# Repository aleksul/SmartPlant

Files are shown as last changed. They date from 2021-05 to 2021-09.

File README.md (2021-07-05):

# SmartPlant

SmartPlant is a simple project that will help you automate watering of your plants.

## Design

Simple and industrial design is easy for 3d printing. Look at this beauty:

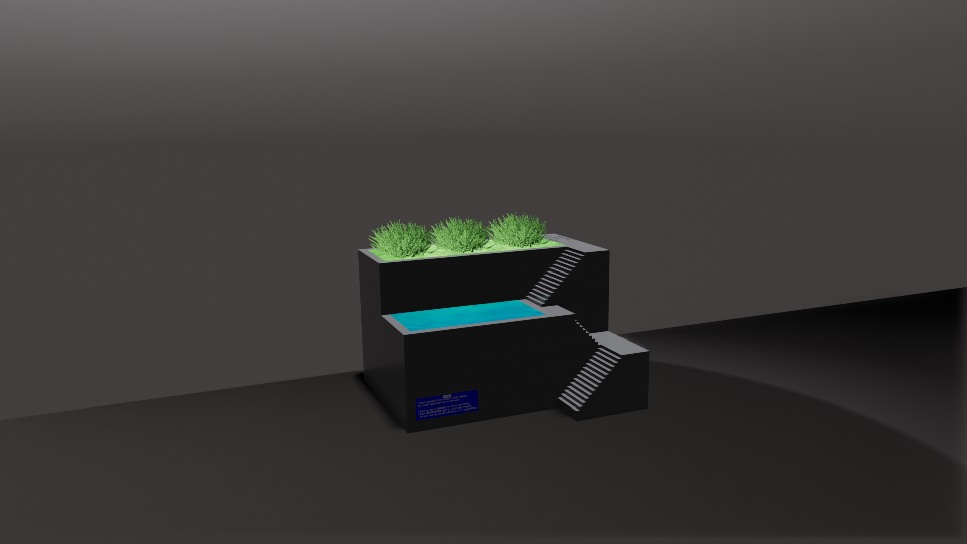
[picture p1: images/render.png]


## Custom PCB

Custom PCB will polish the look of the final product and make assembling even more simple and fun.

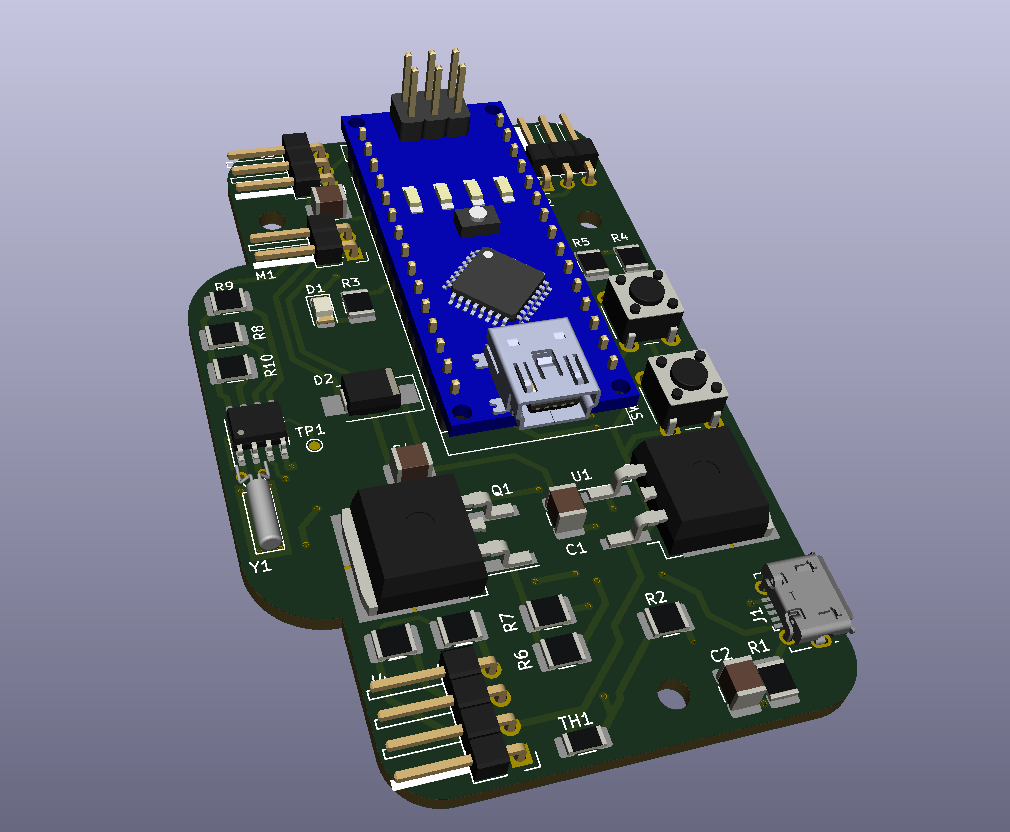
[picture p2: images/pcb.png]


## Ease of modification

Make a fork and rebuild as you want to! 

You can edit any part of this project with open source software such as

- KiCad for schematics and PCB design, 
- FreeCad for 3d modeling, 
- Arduino IDE for code.

## Want to build the same on your own?

Follow the [wiki](https://github.com/Aleksul/SmartPlant/wiki) for Gerber files, bill of materials and more.

## Struggling?

Feel free to open an issue, merge-request or contact me via [Telegram](t.me/aleksul).

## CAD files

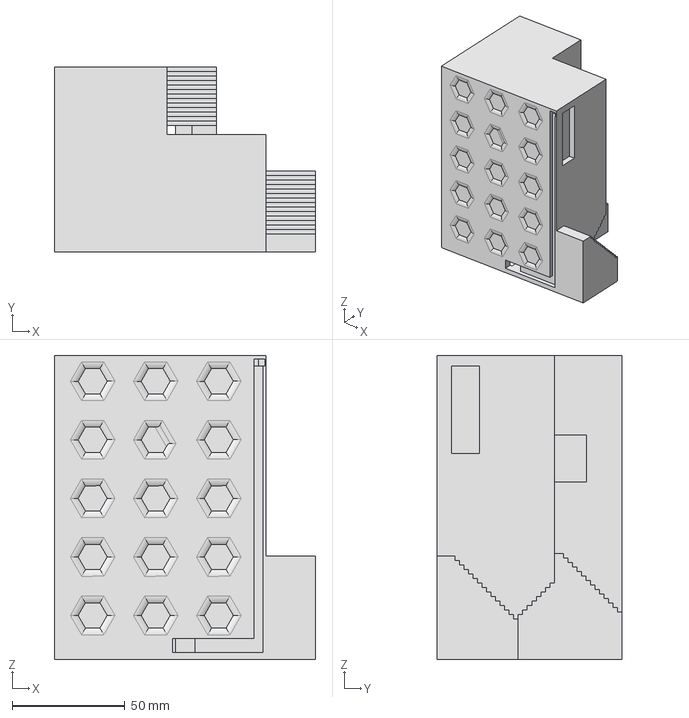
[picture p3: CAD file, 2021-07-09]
3d-models/housing.stp
116.0 x 82.0 x 135.0 mm

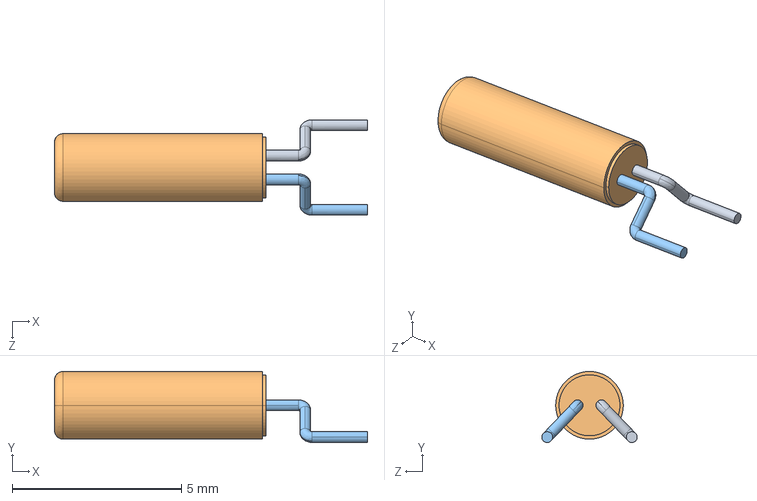
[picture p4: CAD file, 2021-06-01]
hardware/3d models/crystal.STEP
9.25 x 2.10 x 2.82 mm

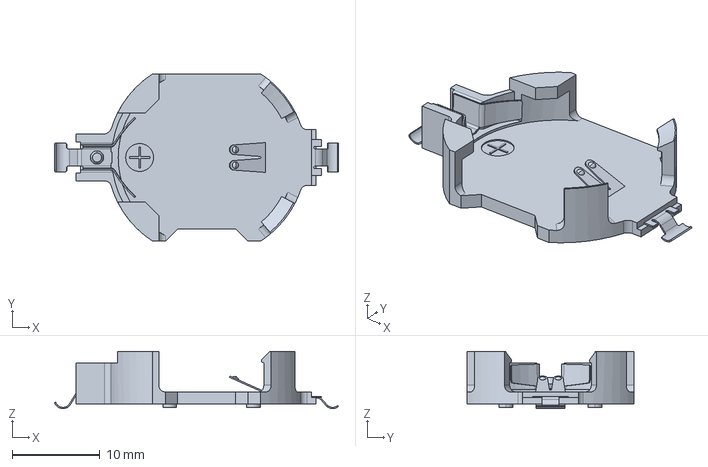
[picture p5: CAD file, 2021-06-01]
hardware/3d models/cr2032.stp
32.3 x 19.1 x 6.53 mm

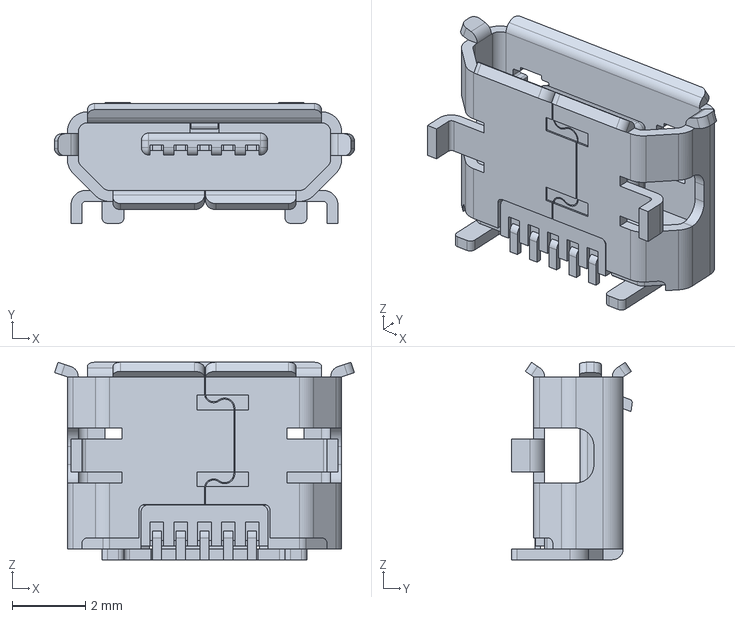
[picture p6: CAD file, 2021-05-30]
hardware/3d models/microusb.stp
8.20 x 3.30 x 5.40 mm

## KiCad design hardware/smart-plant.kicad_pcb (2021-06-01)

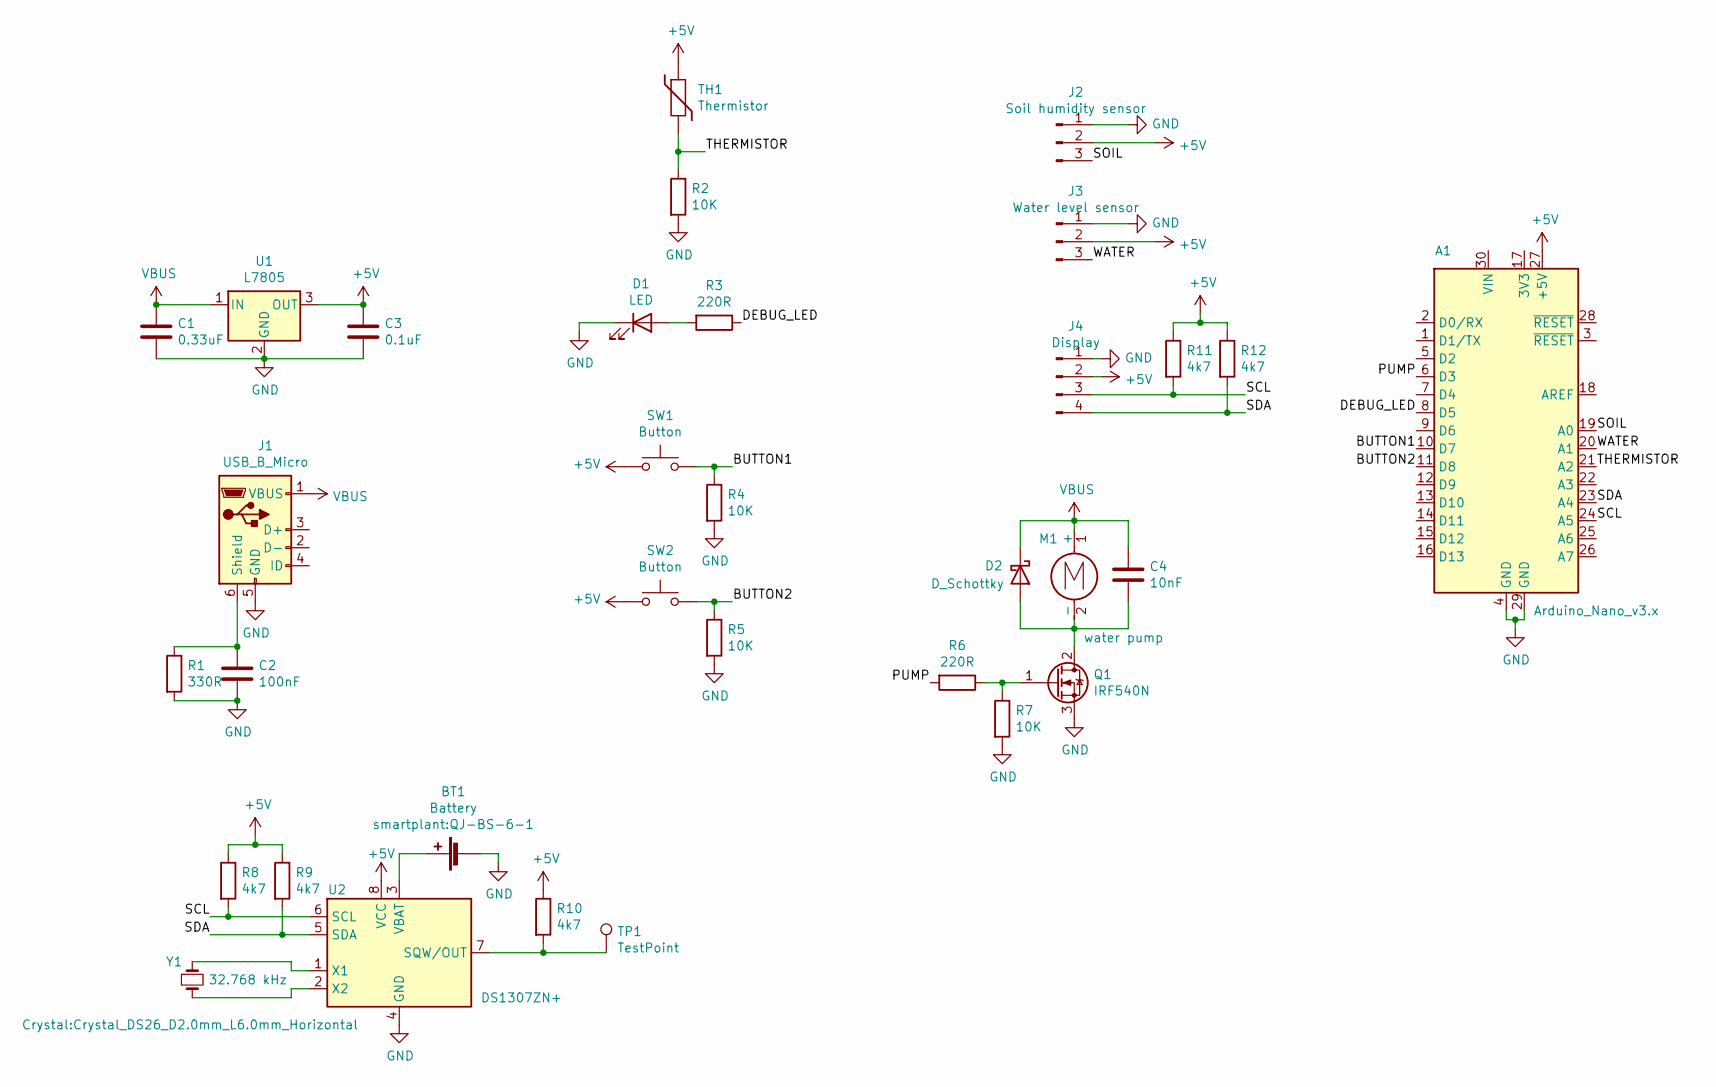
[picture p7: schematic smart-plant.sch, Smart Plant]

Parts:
A1: Arduino_Nano_v3.x; Arduino_Nano
BT1: Battery; QJ-BS-6-1
C1: 0.33uF; C_1210_3225Metric_Pad1.33x2.70mm_HandSolder
C2: 100nF; C_1210_3225Metric_Pad1.33x2.70mm_HandSolder
C3: 0.1uF; C_1210_3225Metric_Pad1.33x2.70mm_HandSolder
C4: 10nF; C_1210_3225Metric_Pad1.33x2.70mm_HandSolder
D1: LED; LED_1206_3216Metric
D2: D_Schottky; D_SMB_Handsoldering
J1: USB_B_Micro; USB_Micro-B_Molex-105017-0001
J2: Soil humidity sensor; PinHeader_1x03_P2.54mm_Horizontal
J3: Water level sensor; PinHeader_1x03_P2.54mm_Horizontal
J4: Display; PinHeader_1x04_P2.54mm_Horizontal
M1: water pump; PinHeader_1x02_P2.54mm_Horizontal
Q1: IRF540N; TO-263-2
R1: 330R; R_1210_3225Metric_Pad1.30x2.65mm_HandSolder
R2, R4, R5, R7: 10K; R_1210_3225Metric_Pad1.30x2.65mm_HandSolder
R3, R6: 220R; R_1210_3225Metric_Pad1.30x2.65mm_HandSolder
R8, R9, R10, R11, R12: 4k7; R_1210_3225Metric_Pad1.30x2.65mm_HandSolder
SW1, SW2: Button; SW_PUSH_6mm_H4.3mm
TH1: Thermistor; R_1206_3216Metric_Pad1.30x1.75mm_HandSolder
TP1: TestPoint; TestPoint_Pad_D1.0mm
U1: L7805; TO-263-2
U2: DS1307ZN+; SOIC-8_3.9x4.9mm_P1.27mm
Y1: 32.768 kHz; Crystal_DS26_D2.0mm_L6.0mm_Horizontal

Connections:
+5V: A1.27 (+5V), C3.1, J2.2, J3.2, J4.2, R8.1, R9.1, R10.1, R11.1, R12.1, SW1.1, SW2.1, TH1.1, U1.3 (OUT), U2.8 (VCC)
/BUTTON1: A1.10 (D7), R4.1, SW1.2
/BUTTON2: A1.11 (D8), R5.1, SW2.2
/DEBUG_LED: A1.8 (D5), R3.1
/PUMP: A1.6 (D3), R6.2
/SCL: A1.24 (A5), J4.3, R8.2, R11.2, U2.6 (SCL)
/SDA: A1.23 (A4), J4.4, R9.2, R12.2, U2.5 (SDA)
/SOIL: A1.19 (A0), J2.3
/THERMISTOR: A1.21 (A2), R2.1, TH1.2
/WATER: A1.20 (A1), J3.3
GND: A1.4 (GND), A1.29 (GND), BT1.2 (-), C1.2, C2.2, C3.2, D1.1 (K), J1.5 (GND), J2.1, J3.1, J4.1, Q1.3 (S), R1.2, R2.2, R4.2, R5.2, R7.2, U1.2 (GND), U2.4 (GND)
unnamed: BT1.1 (+), U2.3 (VBAT)
unnamed: C2.1, J1.6 (Shield), R1.1
unnamed: C4.2, D2.2 (A), M1.2 (-), Q1.2 (D)
unnamed: D1.2 (A), R3.2
unnamed: Q1.1 (G), R6.1, R7.1
unnamed: R10.2, TP1.1, U2.7 (SQW/OUT)
unnamed: U2.1 (X1), Y1.1
unnamed: U2.2 (X2), Y1.2
VBUS: C1.1, C4.1, D2.1 (K), J1.1 (VBUS), M1.1 (+), U1.1 (IN)

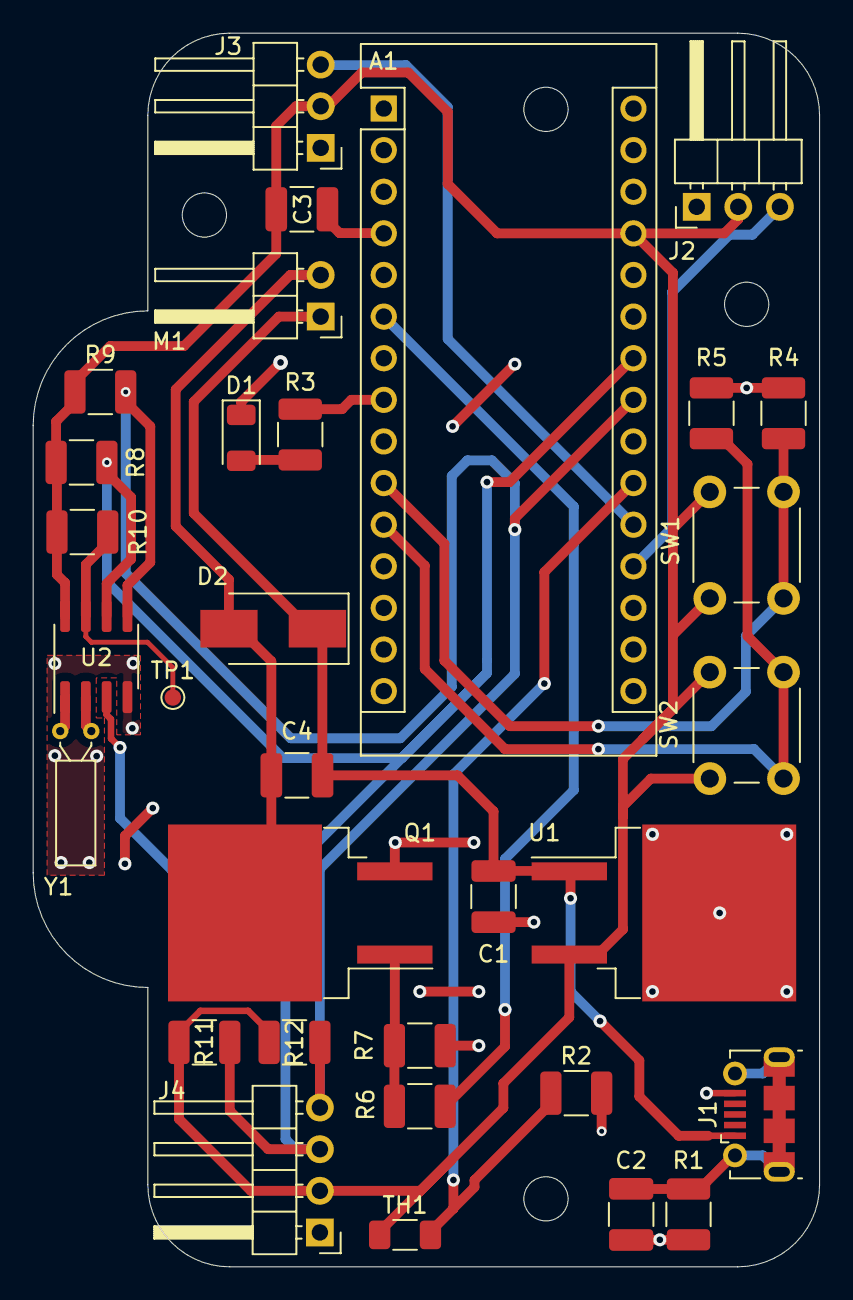
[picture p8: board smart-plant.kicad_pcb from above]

Board: 2 copper layers, 48.0 x 75.3 mm, 33 parts (1 on the bottom side), 20 nets.

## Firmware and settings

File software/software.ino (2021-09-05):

#include <Wire.h>

#include <EEPROM.h>

#include "RTClib.h"
RTC_DS1307 RTC;

#include "Adafruit_GFX.h"
#include "Adafruit_SSD1306.h"

Adafruit_SSD1306 display(128, 32, &Wire, -1);

#define SOIL_SENSOR A0
#define THERMISTOR A2
#define BUTTON1 7
#define BUTTON2 8
#define LED 5
#define PUMP 3

#define PUMP_SEC 15

#define WATER_EVERY_N_SECONDS 259200L

uint16_t maximum_soil_moistry_level = 512;

DateTime future;

String message = "";

void setup()
{
  pinMode(SOIL_SENSOR, INPUT);
  pinMode(THERMISTOR, INPUT);
  pinMode(BUTTON1, INPUT);
  pinMode(BUTTON2, INPUT);
  pinMode(LED, OUTPUT);
  pinMode(PUMP, OUTPUT);
  pinMode(LED_BUILTIN, OUTPUT);

  Wire.begin();

  if (!display.begin(SSD1306_SWITCHCAPVCC, 0x3C)){
    digitalWrite(LED_BUILTIN, HIGH);
    abort(); 
  }
  
  display.clearDisplay();
  display.setTextColor(SSD1306_WHITE);
  display.setCursor(3, 11);
  display.setTextSize(2);
  display.println("SmartPlant");
  display.display();
  delay(3000);
  display.clearDisplay();

  if (!RTC.begin()) {
    digitalWrite(LED_BUILTIN, HIGH);
    abort(); 
  }

  if (! RTC.isrunning()) {
    RTC.adjust(DateTime(F(__DATE__), F(__TIME__)));
  }

  DateTime now = RTC.now();
  future = DateTime(now.unixtime() + WATER_EVERY_N_SECONDS);

  EEPROM.get(2, maximum_soil_moistry_level);

  
}

void loop()
{
  checkButtons();
  DateTime now = RTC.now();
  String old_message = message;
  updateMessage(now, analogRead(SOIL_SENSOR));
  if (old_message != message) {
    updateDisplay();
  }
  if (now.unixtime() >= future.unixtime() && analogRead(SOIL_SENSOR) < maximum_soil_moistry_level) {
    future = DateTime(now.unixtime() + WATER_EVERY_N_SECONDS);
    digitalWrite(PUMP, HIGH);
    delay(PUMP_SEC);
    digitalWrite(PUMP, LOW);
  }
  delay(10);
}

void updateMessage(DateTime now, uint16_t soil) {
  message = "Next watering\n";
  message += "in " + String(future.unixtime() - now.unixtime()) + "s\n";
  if (soil >= maximum_soil_moistry_level) {
    message += "Soil is moist enough";
  }
}

void updateDisplay() {
  display.clearDisplay();
  display.setTextSize(1);
  display.setCursor(0, 0);
  display.println(message);
  display.display();
}

void checkButtons() {
  if (digitalRead(BUTTON2) == HIGH) {
    delay(10);
    if (digitalRead(BUTTON2) == HIGH) {
      maximum_soil_moistry_level = analogRead(SOIL_SENSOR) + 10;
      EEPROM.put(2, maximum_soil_moistry_level);
      digitalWrite(LED, HIGH);
      delay(1000);
      digitalWrite(LED, LOW);
    }
  }
}

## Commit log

2021-05-30 Add schematic and PCB
    [microusb.stp, smart-plant.kicad_pcb, smart-plant.sch]
2021-06-01 Add RTC
    [cr2032.stp, crystal.STEP, smart-plant.kicad_pcb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]
2021-07-03 Add pcb and case renders
2021-07-05 Add jlcpcb gerber
2021-07-09 Add 3d model
    [housing.stp]
